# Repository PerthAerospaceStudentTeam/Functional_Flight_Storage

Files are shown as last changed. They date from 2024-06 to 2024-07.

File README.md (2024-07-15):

# Functional Flight Storage
Secondary Storage for PAST Cubesat

# Project Structure
- All supporting documentation can be found in `support-documents`
- `usage` contains the information on how to use and interface with the storage chips
  - `hardware` contains the files related to the hardware of the flight storage
    - Corresponding PCB schematics can be found in `pcbs`
      - `gerbers` contain the ready to use schematics
      - `altium` contains the source altium files
    - `gridfinity-mount` contains the information on how to mount the storage chips to the gridfinity specs [found here](https://github.com/PerthAerospaceStudentTeam/Modular_FlatSat-Style_Avionics_Testbed)
  - `software` contains the files related to the software of the flight storage
    - `testing` contains all testing logic and the outputs from them
    - `W25N01GVSFIG-storage-driver` contains the driver for the W25N01GVSFIG chip

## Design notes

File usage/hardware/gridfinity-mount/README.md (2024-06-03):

# Overview
Simple design, all three chips are placed on the same mount
- This reduces waste of space and also printing three mounts for the chips
- Tolerances and location of holes for headers are not exact, this is a simple mount for prototyping

Printed with no supports, no rafting, 10% infil using PLA

# Usage
The following files contain the same model in different formats:
 - FFS_Mount_rev1.3mf
 - FFS_Mount_rev1.stl

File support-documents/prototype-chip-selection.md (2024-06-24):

# Overview

There are many chips that can be used for storage. All are to be automotive grade, preferably aerospace grade. This project will focus on the following 3:

## NAND Flash

On paper, the most desirable form of memory. It is non-volatile, high capacity, and cheaper. The downsides are the limited amount of write cycles - this could prove fatal in a mission critical environment

[Chip 1](https://au.mouser.com/ProductDetail/Winbond/W25N01GVSFIG?qs=qSfuJ%2Bfl%2Fd5wRcUOkRc5Cw%3D%3D)

- SPI, 25mA

#### Reasons for selection

- Used by Binar
- Low cost to storage space
- Easy to interface with

#### Reasons for not using

- (Relatively) High current consumption

[Chip 2](https://au.mouser.com/ProductDetail/Micron/MT29F2G08ABAEAWP-AATXE-TR?qs=j%252B1pi9TdxUaMl26HJ%252Bo32A%3D%3D)

- Parallel, 35mA, typ 25mA

#### Reasons for selection

- Automotive grade

#### Reasons for not using

- Needs a LOT of GPIO pins
- Expensive (For NAND)

## NOR Flash

Similar to NOR flash but with much higher read/write speeds. Costs more

[Chip 1](https://au.mouser.com/ProductDetail/Renesas-Dialog/AT25EU0081A-SSUN-T?qs=HoCaDK9Nz5cZm9CJYdZrgw%3D%3D)

- SPI, 3mA, typ 1.6mA

#### Reasons for selection

- VERY low current consumption
- Very high read/write rates

#### Reasons for not using

- Not high storage capacity (may be good as a bootloader for firmware?)

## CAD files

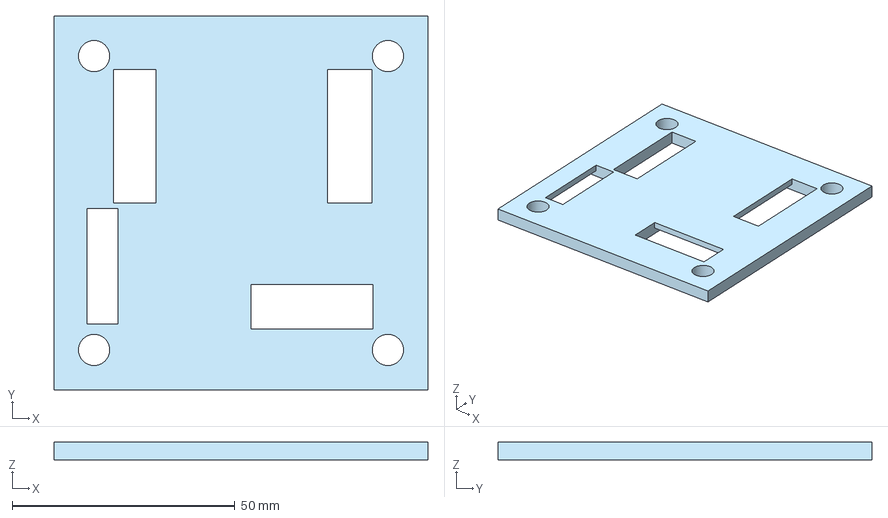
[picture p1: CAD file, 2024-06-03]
usage/hardware/gridfinity-mount/FFS_Mount_rev1.3mf
84.0 x 84.0 x 4.00 mm

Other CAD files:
usage/hardware/gridfinity-mount/FFS_Mount_rev1.stl

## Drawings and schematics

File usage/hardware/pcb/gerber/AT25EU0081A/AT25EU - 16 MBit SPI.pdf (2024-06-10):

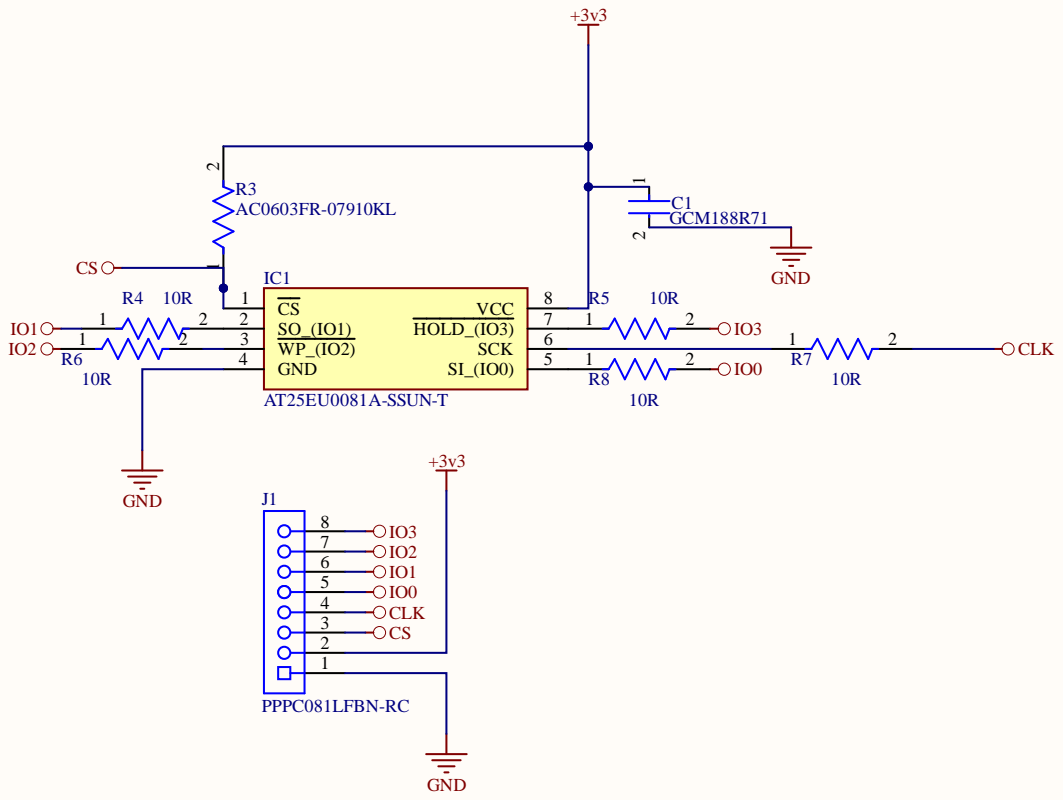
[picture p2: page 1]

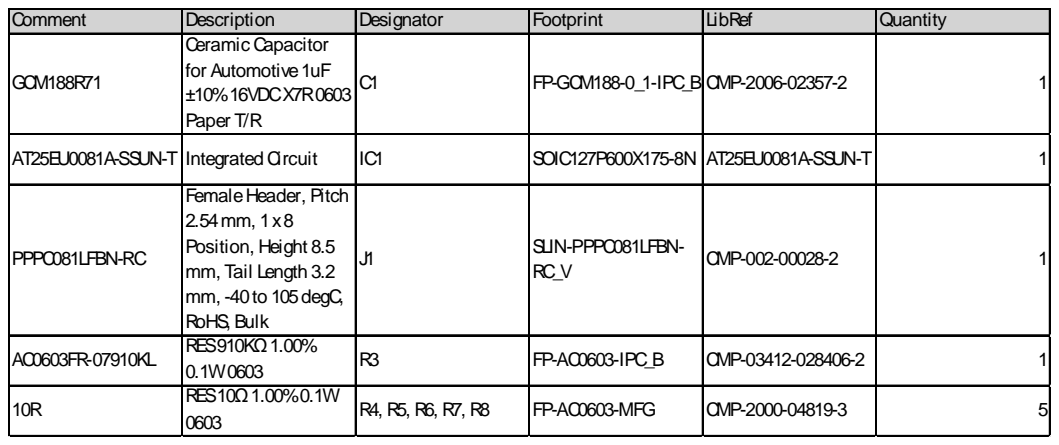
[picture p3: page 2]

Comment | Description | Designator | Footprint | LibRef | Quantity
GCM188R71 | Ceramic Capacitor for Automotive1uF ±10%16VDCX7R0603 Paper T/R | C1 | FP-GCM188-0_1-IPC_B CMP-2006-02357-2 | | 1

AT25EU0081A-SSUN-T | Integrated Circuit | IC1 | SOIC127P600X175-8N | AT25EU0081A-SSUN-T | 1

PPPC081LFBN-RC | FemaleHeader, Pitch 2.54mm, 1x8 Position, Height 8.5 mm, Tail Length 3.2 mm, -40to 105degC, RoHS, Bulk | J1 | SLIN-PPPC081LFBN-RC_V | CMP-002-00028-2 | 1

AC0603FR-07910KL | RES910KΩ1.00% 0.1W0603 | R3 | FP-AC0603-IPC_B | CMP-03412-028406-2 | 1

10R | RES10Ω1.00%0.1W 0603 | R4, R5, R6, R7, R8 | FP-AC0603-MFG | CMP-2000-04819-3 | 5

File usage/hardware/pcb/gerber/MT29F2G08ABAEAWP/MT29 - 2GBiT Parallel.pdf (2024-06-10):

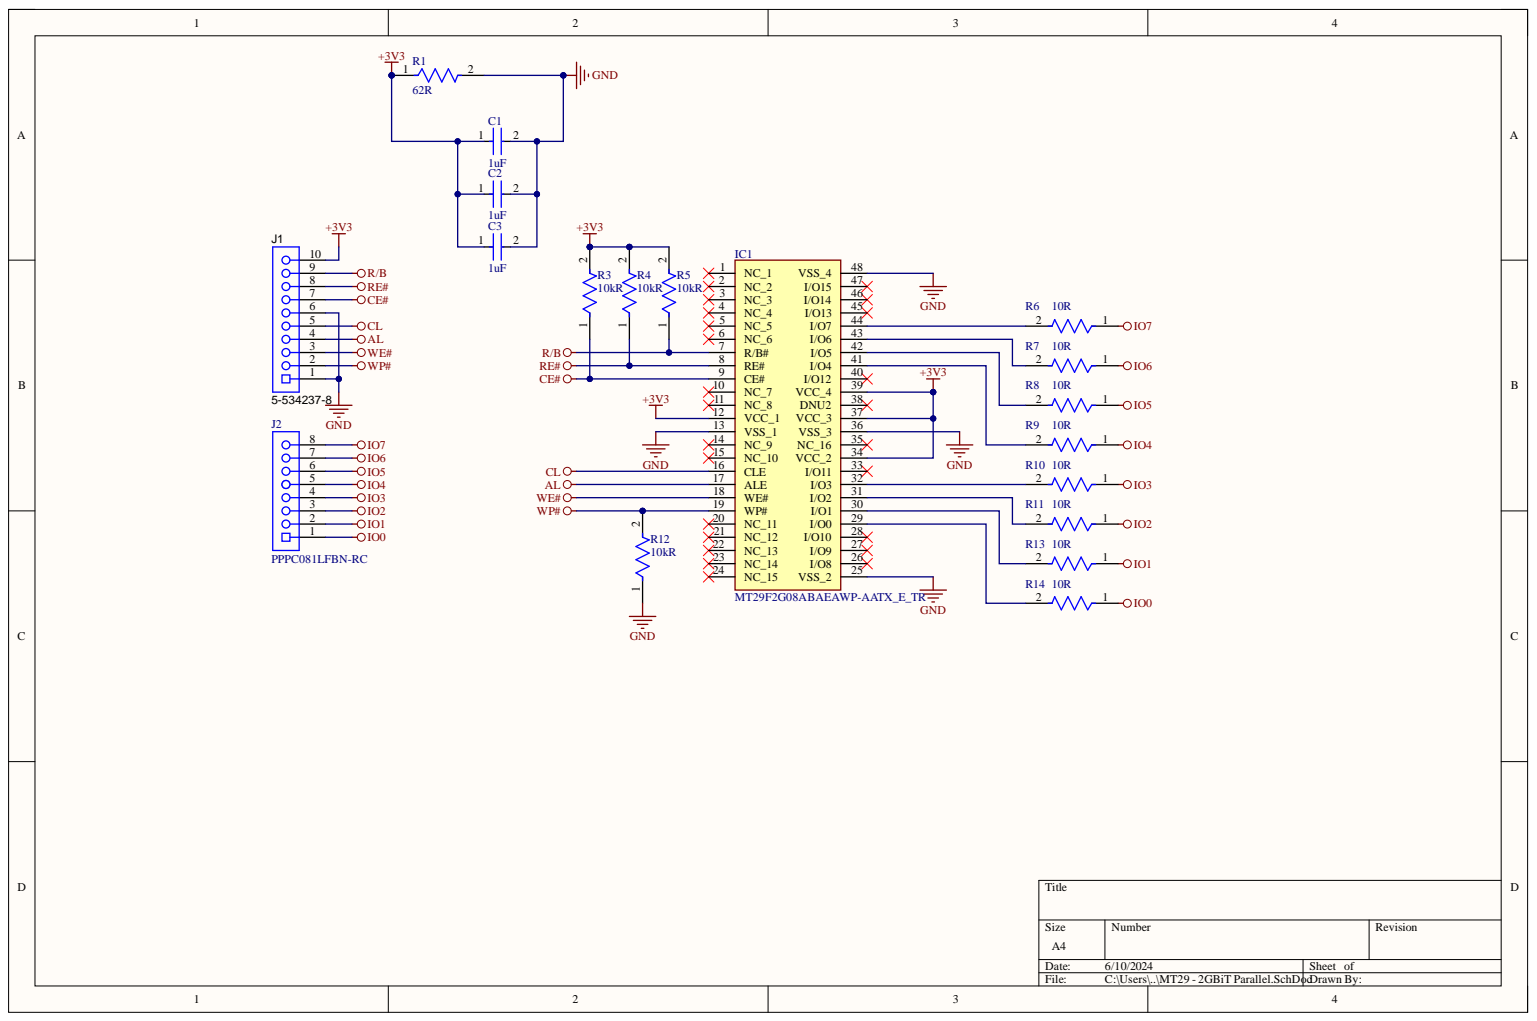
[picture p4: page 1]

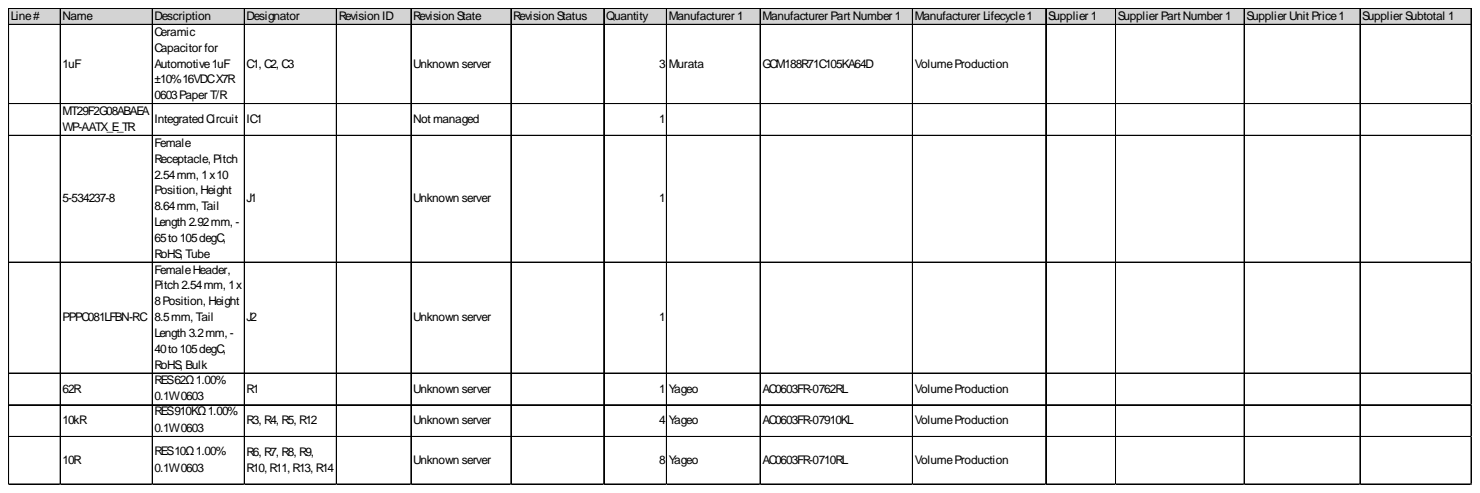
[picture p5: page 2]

Line# | Name | Description | Designator | Revision ID | Revision State | Revision Status | Quantity | Manufacturer 1 | Manufacturer Part Number 1 | Manufacturer Lifecycle1 | Supplier 1 | Supplier Part Number 1 | Supplier Unit Price1 | Supplier Subtotal 1

1uF | Ceramic Capacitor for Automotive1uF ±10%16VDCX7R 0603Paper T/R | C1, C2, C3 | | Unknown server | | 3 Murata | | GCM188R71C105KA64D | VolumeProduction

MT29F2G08ABAEA WP-AATX_E_TR | Integrated Circuit | IC1 | | Not managed | | 1

5-534237-8 | Female Receptacle, Pitch 2.54mm, 1x10 Position, Height 8.64mm, Tail Length 2.92mm, -65to 105degC, RoHS, Tube | J1 | | Unknown server | | 1

PPPC081LFBN-RC | FemaleHeader, Pitch 2.54mm, 1x 8Position, Height 8.5mm, Tail Length 3.2mm, -40to 105degC, RoHS, Bulk | J2 | | Unknown server | | 1

62R | RES62Ω1.00% 0.1W0603 | R1 | | Unknown server | | 1 Yageo | | AC0603FR-0762RL | VolumeProduction

10kR | RES910KΩ1.00% 0.1W0603 | R3, R4, R5, R12 | | Unknown server | | 4 Yageo | | AC0603FR-07910KL | VolumeProduction

10R | RES10Ω1.00% 0.1W0603 | R6, R7, R8, R9, R10, R11, R13, R14 | | Unknown server | | 8 Yageo | | AC0603FR-0710RL | VolumeProduction

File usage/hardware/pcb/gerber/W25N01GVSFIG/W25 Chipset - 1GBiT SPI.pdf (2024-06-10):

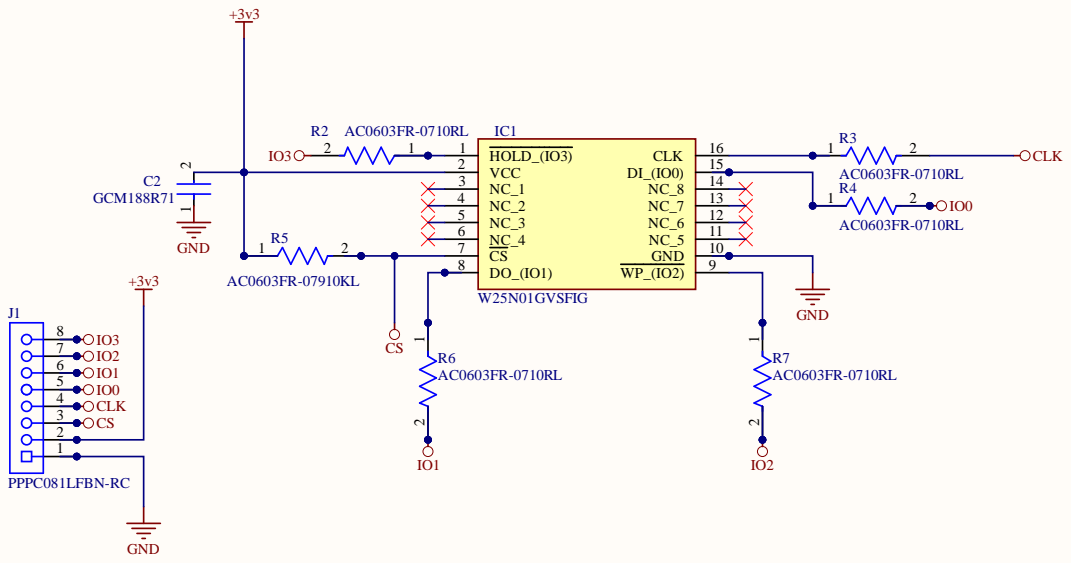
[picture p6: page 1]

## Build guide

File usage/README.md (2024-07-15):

# Hardware

To use the chip in a hardware setting, simply take the Altium files found in [`/hardware/pcb/altium`](https://github.com/PerthAerospaceStudentTeam/Functional_Flight_Storage/tree/main/usage/hardware/pcb/altium), and place them in the desired project.

The pinouts are as follows

| Pin  | Connect | Use |
| ---- | --- | --- |
| +3v3 | +3v3 | Provide power to the board |
| GND  | GND | Provide ground to the board |
| CLK  | CLK | Provides the clock signal - can be connected to external clock provided it is shared between chips |
| IO0  | QSPI0 | Data I/O - see image for STM32 ref. |
| IO1  | QSPI1 | Data I/O - see image for STM32 ref. |
| IO2  | QSPI2 | Data I/O - see image for STM32 ref. |
| IO3  | QSPI3 | Data I/O - see image for STM32 ref. |

For an STM32 Nucleo (the development used), the following QSPI pinout can be used

pinout

For a dedicated MCU, connect the corresponding QSPI lines to the memory

The pinouts for the parallel interface are as follows for the raspberry pi pico
| Pin  | Connect | Use |
| ---- | --- | --- |
| +3v3 | 3V3(Out)| Provide power to the board |
| GND  | GND | Provide ground to the board |
| WP#  | GP19 | Write Protect active low - Pulled low |
| WE#  | GP18 | Write Enable active low |
| AL | GP15 | Address Latch Enable - Load address from IO into address register |
| CL | GP14 | Command Latch Enable - Load address from IO into command register |
| CE#  | GP17 | Chip enable active low - Pulled high |
| RE#  | GP16 | Read enable active low - Pulled high |
| RB#  | N/C | Ready/Busy active low - Pulled up |
| IO0  | GP6 | Data I/O |
| IO1  | GP7 | Data I/O |
| IO2  | GP8 | Data I/O |
| IO3  | GP9 | Data I/O |
| IO4  | GP10 | Data I/O |
| IO5  | GP11 | Data I/O |
| IO6  | GP12 | Data I/O |
| IO7  | GP13 | Data I/O |

The pinouts for the parallel interface are as follows for the stm32
| Pin  | Connect | Use |
| ---- | --- | --- |
| +3v3 | 3v3 | Provide power to the board |
| GND  | GND | Provide ground to the board |
| WP#  | PD_7 | Write Protect active low - Pulled low |
| WE#  | PD_5 | Write Enable active low |
| AL | PD_12  | Address Latch Enable - Load address from IO into address register |
| CL | PD_11  | Command Latch Enable - Load address from IO into command register |
| CE#  | PC_8  | Chip enable active low - Pulled high |
| RE#  | PD_4 | Read enable active low - Pulled high |
| RB#  | PD_6 | Ready/Busy active low - Pulled up |
| IO0  | PD_14  | Data I/O |
| IO1  | PD_15  | Data I/O |
| IO2  | PD_0 | Data I/O |
| IO3  | PD_1 | Data I/O |
| IO4  | PE_7 | Data I/O |
| IO5  | PE_8 | Data I/O |
| IO6  | PE_9 | Data I/O |
| IO7  | PE_10  | Data I/O |

# Software
### W25 STM32 Example code:
_Note: Whilst it is written in Rust, the command set is the same in CPP. If you want this driver to be compiled for CPP please message Sean on discord_
```rust
    let mut w25 = W25::init(qspi);
    // Test 1 - Grab the ID of the chip
    let id = w25.get_id().unwrap();
    rprintln!("Got id: {:x?}", id);
    w25.reset();
    // Test 2 - we need to erase our blocks first
    //Erase block erases a given block
    w25.erase_block(0).unwrap();
    let text = "Hello World!".as_bytes();
    // write_data takes a given set of data, and writes it to an address. It will add a 0xfe byte at the end to signify where the data ends
    w25.write_data(0, text).unwrap();
    let mut dest = [0xff; 11];
    // read_known will read out the data if you already know the size - the buffer to write to must be less than or equal to the data you are expecting
    w25.read_known(0, &mut dest).unwrap();
    // Test 3 - again, we erase our block first
    w25.erase_block(0).unwrap();
    w25.write_data(0, DATA.as_bytes()).unwrap();
    let mut dest = [0xff; 40122];
    w25.read_known(0, &mut dest).unwrap();

    // read_data will read until there is a 0xfe byte, then it will break
    // the data buffer must be equal to or greater than the size you are expecting
    w25.read_data(0, &mut dest).unwrap();
```
### MT29 STM32 FMC example code:
_Note: Message Raph on discord for any questions_
```cpp
HAL_NAND_Reset(&hnand1);
NAND_IDTypeDef id;
HAL_NAND_Read_ID(&hnand1, &id);

//HAL_NAND_ECC_Enable(&hnand1);
HAL_NAND_Read_Status(&hnand1);
uint8_t hello[2112];
uint8_t h[12] = {'H', 'e', 'l', 'l', 'o', ' ', 'W', 'o', 'r', 'l', 'd', '!'};

NAND_AddressTypeDef pAddress;
pAddress.Plane = 0;
pAddress.Block = 0;
pAddress.Page = 0;
// Test 2
HAL_NAND_Read_Page_8b(&hnand1, &pAddress, &hello, 1);

HAL_NAND_Write_Page_8b(&hnand1, &pAddress, &h, 1);

HAL_NAND_Read_Page_8b(&hnand1, &pAddress, &hello, 1);

pAddress.Plane = 0;
pAddress.Block = 1;
pAddress.Page = 0;
uint8_t data[64*2112];

// Test 3
uint32_t tick = HAL_GetTick();
HAL_NAND_Read_Page_8b(&hnand1, &pAddress, &data, 64);
tick = HAL_GetTick() - tick;

pAddress.Plane = 0;
pAddress.Block = 2;
pAddress.Page = 0;
//uint32_t tick2 = HAL_GetTick();
//HAL_NAND_Erase_Block(&hnand1, &pAddress);
//tick2 = HAL_GetTick() - tick2;

uint32_t tick3 = HAL_GetTick();
HAL_NAND_Write_Page_8b(&hnand1, &pAddress, &data, 64);
tick3 = HAL_GetTick() - tick3;
```
### Python ONFI Driver
There are three drivers, any one of them should be able to run, however they have their differences
- ONFIDriver.py is the default driver, it should run normal with no errors
- ONFIDriver_2.py is nearly identical to the default driver, however it has removed the fanatics of the wait times, assuming that the program is running slow enough where the wait times will be reached, however in practice, there is no observed large difference with the default driver in terms of speed (more testing required)
- ONFIDriverParallel.py is similar to the default driver, however PIO is used to read pins, which increases speed dramatically, leading to about 30% increase in speed for reading, PIO is NOT used to write to the pins, due to problems (TODO: Fix PIO write), however due to write not requiring a change of Pin state, it is already quick enough for programming the NAND chip, it would however still improve the overall speed. There is a few observed problems with using the PIO driver, due to using assembly, I do not fully understand how PIO works, and so it may sometimes have previous bytes in the registers and may include those in the next function. When calling status, it may also bit shift the values, causing a problem

Refer to [here](https://github.com/RaphGamingz/BasicONFIDriver/tree/main) for the driver functionality

## File Structure
- It is recommended to use the [`littlefs`](https://github.com/littlefs-project/littlefs) library to create a usable file structure for the device.

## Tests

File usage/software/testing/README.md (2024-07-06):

## Testing Regime

All chips that use SPI will be done using the [`SPI Memory`](https://github.com/Marzogh/SPIMemory) package. This package does have a built in diagnostics routine, to test performance of all commands. This can be run through the testing regime program
For ease of use, a complete testing regime has been written in order to make testing a lot easier. It can be found in `cpp-testing-regime`. 
Note that it has been built with [PlatformIO](https://platformio.org/), and should be opened with it in order to make best use of the tooling
The code has been written for an Arduino-based D1 Mini, as that is the only 3v3 logic board I had lying around to test with. Using a differnt board should be as simple as changing the board defined in `platform.ini`, provided it is supported by the [SPIMemory](https://github.com/Marzogh/SPIMemory) library

After some tests, it was found that the W25N01GVSFIG did not work very well with the [`SPI Memory`](https://github.com/Marzogh/SPIMemory) package, and so custom drivers and testing routines were developed

## ONFIDriver

The MT29F2G08ABAEAWP chip does not have any off the self drivers that we can use. Because of this, a custom driver has been written in Python in order to evaluate the performance of the chip. Whilst Python is not the fastest language, it will suffice to test a) whether this chip works and b) how well it works

## FMC NAND Driver

It was found that on the STM32, the FMC NAND Driver can be used for the MT29F2G08ABAEAWP chip

## Custom Driver for the W25N01GVSFIG
Whilst the [`SPI Memory`](https://github.com/Marzogh/SPIMemory) did have good support for the chips, it did not support many of the commands for the W25N01GVSFIG. A custom driver was written in Rust (mainly because I wasn't really thinking and wanted to try something new)

# Test Suite

#### Test Zero - Connection Evaluation

This test is quite simple - using a multimeter, we will evaluate all physical connections are connected

#### Test One - Read ID

We will attempt to read the ID from the storage chip. This is to validate that the chip is functional

#### Test Two - Basic Test

We will write 12 bytes to the storage chip. This will be done with the string `Hello World!`. The goal if this test is to validate that we can write data to the chip.

Once the data is written, it will be read back. The test is successful when the complete string is read back

We can use the example code on the SPI Memory page [here](https://github.com/Marzogh/SPIMemory/blob/master/examples/readWriteString/readWriteString.ino)

#### Test Three - Running Test

We will write 40 Kilobytes of data. This is to test overall performance of the chip. The sample data can be found in `data.txt`

The following equipment will be used

- Multimeter to measure the amperage and voltage
- Oscilloscope to ensure signals are good

The test will be functionally identical to Test One. Timing code will be injected to measure how long the write transfer, and then the subsequent read transfer will take

#### Test Four - Stress Test

The test begins by writing the `data.txt` to the the chip
A thermal camera will be used to measure the temperature of the chip while running
Current will be measured to find the power draw of the chip

# Test Results
| Chip | Test 0 | Test 1 | Test 2 | Test 3 | Test 4 |
|---|---|---|---|---|---|
| W25N01GVSFIG | Y | Y | Y | Y | Y††† |
| MT29F2G08ABAEAWP-AATX:E TR | Y† | Y | Y | Y | Y††† |
| AT25EU0081A-SSUN-T | Y | Y†† | Y†† | | |

† Bridging between contacts of the chip observed, however the contacts are no connects

†† Tested using a D1 mini

††† Temperature difference was negligible & power draw could not be measured

## Summary
| Chip | Read Speed | Write Speed | Number of Pins |
|---|---|---|---|
| W25N01GVSFIG | @240MHz, 158kb/s | @240MHz, 50kb/s  | 4+2=6 |
| MT29F2G08ABAEAWP-AATX:E TR | @200MHz 2.86mb/s typ, 4.02mb/s max  | @200MHz 2.86mb/s | 8+7=15 |
| AT25EU0081A-SSUN-T | 133kb/s | 8.5kb/s | 4+2=6 |

## W25N01GVSFIG
Peak speeds were averaged over three times with the data from Test 3. 
- Peak write took 0.803635 seconds for 40Kb of data (50kb/s). 
- Peak read took 0.251840 for 40Kb of data (158kb/s).

#### Functions supported by the Driver
- Writing a byte and a data structure
- Reading back a byte or a page
- Reading back a data structure of known (slow) or unknown length (slower)

#### Improvements to the Driver
The driver is certainly not the fastest. There a quite a few improvements that could be made to the code. In no particular order
- The driver started out using the QSPI interface. However, the HAL I am using does not support changing between SPI and QSPI between different transaction phases. This means the instruction was being sent across 4 channels, whereas the chip expected it on the MOSI channel only. This was discovered too late in the development, and so QSPI is still being used, but in the SingleLine mode
- The QSPI interface only supports 32 byte transfers at a time, meaning it has to be buffered out which is very slowly
- The HAL also waits between 50-100microseconds between each transaction, which adds up considerably (especially if only 32 bytes is sent at a time)
In theory, QSPI would speed up the chip by 4 times, and various optimisations to the code could result in an additional 1.5 times speed boost.

The Driver also doesn't make full use of the ECC onboard the chip. Whilst we do let the ECC bits get written, and so the chip handles that side of data integrity, we do not poll the status register to see if there is an irrecoverable ECC corruption

With a better driver, the theoretical performance would be
- Write Speed: 250kb/s
- Read Speed: 790 kb/s

## MT29F2G08ABAEAWP-AATX:E TR
Fastest & safest speed reached was 2.86mb/s read and write
Fastest read speed reached was 4.02mb/s, however we are unsure if the data was all read correctly

### FMC NAND Driver
#### Config
Setting all times to 64 HCLK should be safe, as running at 64 MHz, 1 HCLK would be ~16ns, and 64 HCLK would be ~1us, which should be plenty of time

Setup time - highest min is 10ns min (ALE), with exception of 15ns min (CE#)
Hold time - 5ns min

Wait time - (WE high to RE low 60ns min), (ALE to data start 70ns min), (WP# to WE# low 100ns min)

High Z - (RE# high to output high-Z 100ns max)

Erase operation time 0.7-3ms
Program page 200-600us (room temp) - Should read status after, as there is no wait within the driver

ALE to RE# & CLE to RE# delay 10ns min

#### Timings @ 200 MHz
ALE to RE delay & CLE to RE delay would be set to 2 HCLK

200 MHz is not the fastest FMC can run (it can run up to 240 MHz), however it would require non-whole clock cycles to run (probably taking up more time)
Using 200 MHz means that one HCLK is 5ns
The timings would be 3-20-2-20
If we were to push it, it we could try 2-20-1-20

To really push it, 2-10-1-10 was also tested, however data integrity could be a problem (unverified)
- Benefits to this was a faster read speed, but approx same write speed

##### Reading @200 MHz
3-20-2-20: Reading 135168 bytes took 0.047 seconds, giving a speed of ~2.74mb/s

2-20-1-20: Reading 135168 bytes took 0.045 seconds, giving a speed of ~2.86mb/s

2-10-1-10: Reading 135168 bytes took 0.032 seconds, giving a speed of ~4.02mb/s

##### Writing @200 MHz
3-20-2-20: Writing 135168 bytes took 0.045 seconds, giving a speed of ~2.86mb/s

2-20-1-20: Writing 135168 bytes took 0.045 seconds, giving a speed of ~2.86mb/s

2-10-1-10: Writing 135168 bytes took 0.046 seconds, giving a speed of ~2.80mb/s (SLOWER)

#### Timings @ 64 MHz
ALE to RE delay & CLE to RE delay would be set to 1 HCLK

64 MHz is the default speed
The timings would be 2-8-2-8
If we wanted to push the chip, we could try 1-7-1-7

To really push it, 1-1-1-1 was also tested, however data integrity could be a problem (unverified)
##### Reading @64 MHz
With the STM32 at default (unchanged max wait times) settings, reading 135168 bytes took 1.737 seconds, giving a speed of ~77817 bytes per second (~76 kbytes per second)
64-64-64-64: Reading 135168 bytes took 0.517 seconds, giving a speed of ~255kb/s

2-8-2-8: Reading 135168 bytes took 0.137 seconds, giving a speed of ~0.941mb/s

1-7-1-7: Reading 135168 bytes took 0.131 seconds, giving a speed of ~0.984mb/s

1-1-1-1: Reading 135168 bytes took 0.120 seconds, giving a speed of ~1.074mb/s

2-8-2-8: Reading 270336 bytes took 0.275 seconds, giving a speed of ~0.9375mb/s

##### Writing @64 MHz
64-64-64-64: Writing 135168 bytes took 0.418 seconds, giving a speed of ~315kb/s

2-8-2-8: Writing 135168 bytes took 0.146 seconds, giving a speed of ~0.883mb/s

1-7-1-7: Writing 135168 bytes took 0.145 seconds, giving a speed of ~0.889mb/s

1-2-1-1: Writing 135168 bytes took 0.145 seconds, giving a speed of ~0.889mb/s

2-8-2-8: Writing 270336 bytes took 0.291 seconds, giving a speed of ~0.886mb/s

#### Further improvements
The driver does not seem to use the ECC builtin on the chip, this could be enabled
The driver does not use cache sequential read, however it is not supported with ECC, although if software ECC is used, it would possibly be able to improve speeds slightly

### Python ONFI Driver
#### Reading
With the raspberry pi pico using PIO, reading 16800 bytes took 84 seconds, this gives a speed of 200 bytes per second
With a second test, with the raspberry pi pico using PIO, reading 84480 bytes took 404.91 seconds, giving a speed of ~208 bytes per second
With a third test, with the raspberry pi pico using PIO, reading 84480 bytes took 396.167 seconds, giving a speed of ~213 bytes per second
Without PIO, reading 16800 bytes took ~110 seconds, giving a speed of 153 bytes per second

#### Writing
Writing 40kb took 118.622 seconds, giving a time of ~333 bytes per second
With a second test, utilising all bytes in a page, writing 30kb took 76.513 seconds, giving a time of ~522 bytes per second (using the programPageString function, as it may utilise less memory)

This can definitely be improved by using an STM32, or using PIO for read and write on the raspberry pi pico as the chip's max speed is about 84,480,000 bytes per second for read, and 10,560,000 bytes per second for write

For Test 3, the chip has not been tested with a:
- Multimeter to measure the amperage and voltage
- Oscilloscope to ensure signals are good

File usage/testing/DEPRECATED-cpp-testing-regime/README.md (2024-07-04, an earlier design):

# DO NOT USE
This was a testing suite to run on a 3v3 based Arduino board to test the two SPI chips. However, both these chips ended having custom drivers written for them, and the testing was done with an STM32. Because of this, this code was not used. We are leaving it here as reference for the development process

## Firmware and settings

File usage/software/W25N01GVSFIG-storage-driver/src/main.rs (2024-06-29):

#![deny(warnings)]
#![no_main]
#![no_std]

use cortex_m_rt::entry;
use data::DATA;
use rtt_target::{rprintln, rtt_init_print};
use stm32h7xx_hal::{gpio::Speed, pac, prelude::*, timer};

use panic_rtt_target as _;

use storage_driver::W25;

use core::{
    cell::RefCell,
    sync::atomic::{AtomicU32, Ordering},
};

use cortex_m::interrupt::Mutex;

use pac::interrupt;

static OVERFLOWS: AtomicU32 = AtomicU32::new(0);
static TIMER: Mutex<RefCell<Option<timer::Timer<pac::TIM2>>>> = Mutex::new(RefCell::new(None));

mod data;

#[entry]
fn main() -> ! {
    let mut cp = cortex_m::Peripherals::take().unwrap();
    let dp = pac::Peripherals::take().expect("cannot take peripherals");

    // Constrain and Freeze power
    let pwr = dp.PWR.constrain();
    let pwrcfg = pwr.freeze();

    // Constrain and Freeze clock
    let rcc = dp.RCC.constrain();
    let ccdr = rcc.sys_ck(240.MHz()).freeze(pwrcfg, &dp.SYSCFG);

    rtt_init_print!();

    // Acquire GPIO Pins
    let gpiog = dp.GPIOG.split(ccdr.peripheral.GPIOG);
    let gpiob = dp.GPIOB.split(ccdr.peripheral.GPIOB);
    let gpiod = dp.GPIOD.split(ccdr.peripheral.GPIOD);
    let gpioe = dp.GPIOE.split(ccdr.peripheral.GPIOE);

    // Lock CS
    let _qspi_cs = gpiog.pg6.into_alternate::<10>().speed(Speed::VeryHigh);

    //Lock pins
    let sck = gpiob.pb2.into_alternate().speed(Speed::VeryHigh);
    let io0 = gpiod.pd11.into_alternate().speed(Speed::VeryHigh);
    let io1 = gpiod.pd12.into_alternate().speed(Speed::VeryHigh);
    let io2 = gpioe.pe2.into_alternate().speed(Speed::VeryHigh);
    let io3 = gpiod.pd13.into_alternate().speed(Speed::VeryHigh);

    let mut timer = dp
        .TIM2
        .tick_timer(1.MHz(), ccdr.peripheral.TIM2, &ccdr.clocks);
    timer.listen(timer::Event::TimeOut);

    cortex_m::interrupt::free(|cs| {
        TIMER.borrow(cs).replace(Some(timer));
    });

    unsafe {
        cp.NVIC.set_priority(interrupt::TIM2, 1);
        pac::NVIC::unmask(interrupt::TIM2);
    }

    //Initialize QSPI
    let qspi = dp.QUADSPI.bank1(
        (sck, io0, io1, io2, io3),
        3.MHz(),
        &ccdr.clocks,
        ccdr.peripheral.QSPI,
    );

    let mut w25 = W25::init(qspi);
    // Test 1
    let id = w25.get_id().unwrap();
    rprintln!("Got id: {:x?}", id);
    w25.reset();
    // Test 2 - we need to erase our blocks first
    w25.erase_block(0).unwrap();
    let text = "Hello World!".as_bytes();
    let two_t1 = timestamp();
    w25.write_data(0, text).unwrap();
    let two_t2 = timestamp();
    let mut dest = [0xff; 11];
    let two_t3 = timestamp();
    w25.read_known(0, &mut dest).unwrap();
    let two_t4 = timestamp();
    rprintln!(
        "Write time: {}, Read time: {}",
        two_t2 - two_t1,
        two_t4 - two_t3
    );
    // Test 3 - again, we erase our block first
    w25.erase_block(0).unwrap();
    let three_t1 = timestamp();
    w25.write_data(0, DATA.as_bytes()).unwrap();
    let three_t2 = timestamp();
    let mut dest = [0xff; 40122];
    let three_t3 = timestamp();
    rprintln!("Dest length: {}", dest.len());
    w25.read_known(0, &mut dest).unwrap();
    let three_t4 = timestamp();
    rprintln!("Data: {:?}", &dest[40000..40122]);
    rprintln!("Data length: {}", DATA.as_bytes().len());

    rprintln!(
        "Write time: {}, Read time: {}",
        three_t2 - three_t1,
        three_t4 - three_t3
    );

    loop {
        cortex_m::asm::nop();
    }
}

/// Handle timer overflow and count past 32-bits.
///
/// The interrupt should be configured at maximum priority, it won't take very long.
#[interrupt]
fn TIM2() {
    OVERFLOWS.fetch_add(1, core::sync::atomic::Ordering::SeqCst);
    cortex_m::interrupt::free(|cs| {
        let mut rc = TIMER.borrow(cs).borrow_mut();
        let timer = rc.as_mut().unwrap();
        timer.clear_irq();
    })
}

/// Returns the 64-bit number of microseconds since startup
pub fn timestamp() -> u64 {
    let overflows = OVERFLOWS.load(Ordering::SeqCst) as u64;
    let ctr = cortex_m::interrupt::free(|cs| {
        let rc = TIMER.borrow(cs).borrow();
        let timer = rc.as_ref().unwrap();
        timer.counter() as u64
    });
    (overflows << 32) + ctr
}

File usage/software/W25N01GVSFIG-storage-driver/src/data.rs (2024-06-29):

pub const DATA: &str = "Lorem ipsum dolor sit amet, consectetur adipiscing elit. Ut tempus eros quis felis scelerisque, nec auctor elit venenatis. Maecenas ultrices arcu sed urna ullamcorper, at malesuada enim sollicitudin. Donec blandit mauris magna, vitae pharetra risus pretium at. Mauris sapien justo, consectetur ut dignissim eu, rutrum a elit. Sed diam ipsum, elementum at augue ut, vehicula pulvinar arcu. Nullam at elit elementum, mattis purus non, aliquam nisi. Nullam ut risus sed eros gravida laoreet. Nunc finibus, purus eget convallis congue, eros felis rhoncus velit, et ultrices risus purus ac massa. Curabitur eu maximus odio.

Quisque eu leo sagittis odio sollicitudin aliquam non sed lacus. Pellentesque ut auctor metus. Nulla eu diam rutrum, scelerisque odio non, interdum lectus. Nunc viverra sed quam sed malesuada. Morbi blandit mi metus, at varius magna dictum a. Ut pulvinar convallis nibh, lacinia egestas augue sodales eu. Duis egestas, metus nec faucibus rutrum, urna mi dapibus ante, non pharetra felis metus ac elit.

Maecenas vestibulum porta purus vel tincidunt. Proin cursus tortor nec arcu congue aliquam. Cras ultricies aliquet egestas. Pellentesque tellus nulla, fermentum vel lectus eget, consequat dignissim mauris. Donec et tincidunt est. Phasellus pharetra lectus elementum, condimentum orci quis, sollicitudin est. Integer at elementum velit, quis scelerisque eros. Suspendisse eget vehicula justo, vitae euismod augue. Duis tristique imperdiet velit. Mauris malesuada eu mauris id euismod. Cras et magna semper, aliquam ex sed, rhoncus dolor. Mauris vitae pulvinar nisi, ut dapibus magna. Sed sem nibh, sagittis hendrerit imperdiet vel, fringilla at orci. Donec est turpis, auctor ut nisi vitae, fermentum venenatis nulla.

Cras in dignissim enim, faucibus sodales dolor. Maecenas dapibus orci et erat vulputate blandit. Nam eu posuere urna. Donec fermentum, lorem nec facilisis dictum, nulla elit auctor mauris, ut congue lectus orci non enim. Duis non turpis eget leo gravida porta. Aliquam dignissim scelerisque ante, quis maximus mi fermentum id. Morbi sit amet nisi sapien. Suspendisse pulvinar, nibh quis tincidunt lacinia, augue lacus blandit massa, eget tincidunt diam magna sed libero. Aliquam vehicula leo eget risus placerat, tincidunt efficitur augue iaculis. Morbi malesuada dui at fermentum posuere. Duis tempus elit quis velit molestie, ut bibendum quam vulputate. Sed fringilla a lectus ac lobortis.

Pellentesque malesuada nisl tortor, a maximus nunc viverra ac. Sed posuere, ipsum non tincidunt consequat, lacus neque rhoncus ipsum, ut cursus risus metus in tellus. Praesent mi ligula, luctus vel erat eget, ultrices maximus mi. Suspendisse enim elit, volutpat bibendum placerat eget, viverra et purus. In quis imperdiet purus. Integer consectetur sapien sit amet magna elementum, in egestas sapien sodales. Praesent eu risus ac libero blandit laoreet. Vivamus ultrices purus sit amet maximus semper. Nam condimentum tempus odio, in luctus neque feugiat non. Pellentesque dictum, felis quis molestie cursus, elit lacus pellentesque lectus, id porta metus risus ut libero. Pellentesque habitant morbi tristique senectus et netus et malesuada fames ac turpis egestas. Ut consequat blandit est, vitae fringilla nisi tincidunt at. Vestibulum placerat molestie magna at venenatis. Etiam ipsum metus, vulputate non hendrerit placerat, eleifend at sem. Duis a quam congue, consequat nibh eu, iaculis diam. Integer ut sollicitudin neque.

Fusce arcu enim, rhoncus eget ullamcorper a, faucibus a dui. Etiam consequat pharetra euismod. Nullam a felis tristique, tristique enim sed, dignissim enim. Sed bibendum quam magna, at lobortis libero luctus non. Sed quis bibendum dolor. Duis imperdiet euismod nisl, id dignissim eros commodo id. Nam eget egestas enim, eget aliquam mauris. Sed in erat eget tellus aliquet pulvinar ac eget metus. Vivamus sed imperdiet lorem. In cursus, nisi ullamcorper sagittis congue, leo felis viverra ligula, at condimentum arcu erat sed eros. In orci sem, accumsan vitae semper eget, rutrum eget purus. Maecenas vulputate urna porta euismod fringilla.

Nulla neque augue, tempus sit amet mollis a, tristique ac nisl. Nam pharetra ipsum nec ullamcorper molestie. Duis sodales mattis mattis. Duis rhoncus, dui vitae congue elementum, enim ligula lacinia tortor, nec mollis arcu tortor ultricies lorem. Nunc suscipit justo at ornare commodo. Sed tempor mauris et orci molestie, molestie fringilla justo mattis. Phasellus at justo vitae nunc porta imperdiet. Mauris ac leo eu felis iaculis faucibus. Curabitur sapien tortor, luctus sit amet eros nec, ullamcorper egestas velit. Sed lobortis nisl nec lacus egestas viverra. In lobortis lectus ut sapien varius aliquet nec et metus. Suspendisse potenti. Integer aliquam volutpat placerat. Phasellus vitae felis venenatis, facilisis tellus ac, molestie metus.

Pellentesque habitant morbi tristique senectus et netus et malesuada fames ac turpis egestas. Proin elementum quam at nisl volutpat, vitae luctus ipsum maximus. Maecenas nec eros vitae ex consequat efficitur et sed augue. Maecenas massa turpis, iaculis quis velit vel, aliquet placerat purus. Aliquam consequat arcu suscipit dui dapibus vulputate. Morbi condimentum eu lacus ut pretium. Suspendisse quis convallis mauris. Cras varius ligula non velit ultricies elementum. Nulla commodo, neque a viverra rhoncus, urna nulla cursus lorem, nec luctus risus metus nec justo. Duis sed bibendum lorem.

Donec pulvinar ex et congue dignissim. Etiam mollis egestas massa, a ornare lacus gravida ut. Vestibulum ante ipsum primis in faucibus orci luctus et ultrices posuere cubilia curae; Nullam enim justo, fringilla ac erat sed, vehicula scelerisque massa. Nulla vel leo eleifend, mollis sapien id, dignissim mi. In nec turpis et lectus ultricies porttitor sed sit amet ante. Donec consequat tellus enim, id venenatis libero semper at. Aliquam eget pulvinar turpis. Cras id augue a mi molestie convallis. Curabitur pretium diam at velit porttitor luctus. In at hendrerit arcu, dictum scelerisque mauris. Ut ultricies ipsum vitae nunc laoreet bibendum. Nunc facilisis augue eget mi finibus, et egestas urna commodo. Etiam luctus eros tellus, mattis mollis dui auctor ac. Nullam commodo dolor nec dui blandit iaculis. Suspendisse potenti.

Duis ut feugiat magna, quis imperdiet diam. Donec lacinia velit eget mollis sollicitudin. Maecenas vel tellus sed turpis sodales ornare. In ultricies dapibus sapien sit amet cursus. Aliquam vel purus facilisis, aliquam nibh tempus, laoreet risus. Pellentesque porta justo sit amet ultricies pulvinar. Nam in velit a nisi rutrum ultrices. Fusce non augue est. Aliquam a nisi at sapien lobortis varius. Maecenas ut fringilla felis. Nulla risus justo, imperdiet eu lacus auctor, ornare tincidunt tortor.
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

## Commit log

2024-04-09 Update prototype-chip-selection.md with NAND chip
2024-04-09 Update prototype-chip-selection.md
    Added more datasheet links
2024-04-09 Fix prototype-chip-selection.md
2024-05-07 updated prototype chip selection
2024-06-03 Added mounting for Gridfinity
    [FFS_Mount_rev1.3mf, FFS_Mount_rev1.stl]
2024-06-08 Upload driver for MT29
2024-06-10 uploaded testing regime for SPI chips, restructured project slightly
2024-06-10 Uploaded pcb files
    [AT25EU - 16 MBit SPI.SchDoc, AT25EU - Chipset 16MBit SPI.PcbDoc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]
2024-06-13 Added a read id test, also updated the driver files for the MT29
2024-06-15 Updated testing for MT29 chip & improved drivers
2024-06-18 Added a file for some raspberry pi pico resources
2024-06-20 Update README.md with new pinouts for MT29 pi pico & stm32
2024-06-23 Clean up README.md
    Removed the massive block of text showing how to use the driver, and moved to a separate repo
2024-06-23 Update README.md with C++ code from STM32
2024-06-29 added source files for driver, restructured
2024-07-15 Restructure of the repository
    [AT25EU - 16 MBit SPI.SchDoc, AT25EU - Chipset 16MBit SPI.PcbDoc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]
